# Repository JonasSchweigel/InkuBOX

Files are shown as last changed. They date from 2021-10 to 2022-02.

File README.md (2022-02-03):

# InkuBOX
Creating the InkuBOX was a project we realised in the Makerspace at the TUM School of Life Sciences in Weihenstephan.
We came up with the idea to build a cheap incubator for studying plant-pathogen interactions without contaminating surrounding plants / apperations in the lab / growth chamber.
We descided to follow a modular system and tried to combine modules that are enclosed in themselfes for easy repair / adaption / modulation.
After intensive planning and debating of probable difficulties we started to construct our first prototype.
The control system is realized via the open source arduino platform.
Special parts were designed with AutoDesk360 and printed in PLA with a 3D-Printer.
The project tought us how difficult it can be to develop hardware and how much know how is hidden in every little aspect of even such a small and simple machine. 
We very quicly realized that changing one parameter always influences the whole project. 
We learned how to plan efficiently and what has to be considered if changes in the planing have to be implemented at a later stage.
Every single part of the machine influences the others which can be frustrating but in the end, thats what makes the product work.
This project still has lots of opportunities to be further enhanced and could sometime become the blueprint for a cheap and easy to assable phytochamber for laboratories all around the world.
We hope you find some inspiration through this project and feel free to contact us for any questions.
Starting with the InkuBOX.ptx you will most likely understand the project, even if you do not speak german.

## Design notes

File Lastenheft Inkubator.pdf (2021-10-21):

Lastenheft:

Ein Projekt im Makerspace SoSe2021

Projekt: Inkubator zur Anzucht und Kultivierung von Pflanzen und Pilzen in der Phytopathologie

Name: Jonas Schweigel, Franziska Meyer

Definition: Pflanzen- und Pilzinkubator zur Versuchsdurchführung von Pflanze-Pathogen-Interaktionen

Geschlossenes System mit semi-automatisierter Überwachung und Steuerung verschiedener Umweltfaktoren

Größe: Circa 50cmx75cmx50cm

Sensoren:

- Temperatursensor
- Bodenfeuchtigkeitssensor
- Luftfeuchtigkeitssensor
- Wasserstandsensor

Module:

- Heizung
- Wasserpumpe
- Belüftung (Geeignete Umgebung vorausgesetzt)

Anforderungen

Bewässerung:

- Automatischen Einschalten der Wasserpumpe nach Erreichen eines niedrigen Grenzwerts
- Abschalten der Wasserpumpe bei definiertem Grenzwert
- Überlaufschutz

Heizung:

- Automatisches Einschalten, wenn Temperatur unter Grenzwert fällt
- Abschalten nach Erreichen des Temperaturoptimums

Luftfeuchtigkeit:

- Anzeige der Luftfeuchtigkeit

Gantt Diagramm und Projektplanung

Woche | 1 | 19.04.2021 2 | 26.04.2021 3 | 03.05.2021 4 | 10.05.2021 5 | 17.05.2021 6 | 24.05.2021 7 | 31.05.2021 8 | 07.06.2021 9 | 14.06.2021 10 | 21.06.2021 11 | 28.06.2021 12 | 05.07.2021 13 | 12.07.2021 14 | 19.07.2021 15 | 26.07.2021 16 | Urlaub | 30.08.2021 17 | 06.09.2021 18 | 13.09.2021 19 | 20.09.2021 20 | 27.09.2021 21 | 04.10.2021 22 | 11.10.2021 23 12.04.2021

Phase 1
Projektfindung
Planung und Entwurf
Recherche
Phase 2
Einführung Arduino
Beschaffung Hardware
Codierung
Phase 3
CAD Entwürfe 3D Druck
Zusammenbau Hardware
Zusammenbau Elektronik
Testdurchläufe
Abschluss
Optimierung und Problemanalyse

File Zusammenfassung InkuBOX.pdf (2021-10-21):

Zusammenfassung

InkuBOX - Ein Projekt im Makerspace SoSe2021

Projekt: Inkubator zur Anzucht und Kultivierung von Pflanzen und Pilzen in der Phytopathologie

Name: Jonas Schweigel, Franziska Meyer

Definition: Pflanzen- und Pilzinkubator zur Versuchsdurchführung von Pflanze-Pathogen-Interaktionen

Geschlossenes System mit semi-automatisierter Überwachung und Steuerung verschiedener Umweltfaktoren

Größe: Circa 50cmx75cmx50cm

Sensoren:

- Temperatursensor
- Bodenfeuchtigkeitssensor
- Luftfeuchtigkeitssensor
- Wasserstandsensor

Module:

- Heizung
- Wasserpumpe
- Belüftung (Geeignete Umgebung vorausgesetzt)

Anforderungen

Bewässerung:

- Automatischen Einschalten der Wasserpumpe nach Erreichen eines niedrigen Grenzwerts
- Abschalten der Wasserpumpe bei definiertem Grenzwert
- Überlaufschutz

Heizung:

- Automatisches Einschalten, wenn Temperatur unter Grenzwert fällt
- Abschalten nach Erreichen des Temperaturoptimums

Luftfeuchtigkeit:

- Anzeige der Luftfeuchtigkeit

Gantt Diagramm und Projektplanung

Woche | 1 | 19.04.2021 2 | 26.04.2021 3 | 03.05.2021 4 | 10.05.2021 5 | 17.05.2021 6 | 24.05.2021 7 | 31.05.2021 8 | 07.06.2021 9 | 14.06.2021 10 | 21.06.2021 11 | 28.06.2021 12 | 05.07.2021 13 | 12.07.2021 14 | 19.07.2021 15 | 26.07.2021 16 | Urlaub | 30.08.2021 17 | 06.09.2021 18 | 13.09.2021 19 | 20.09.2021 20 | 27.09.2021 21 | 04.10.2021 22 | 11.10.2021 23 12.04.2021

Phase 1
Projektfindung
Planung und Entwurf
Recherche
Phase 2
Einführung Arduino
Beschaffung Hardware
Codierung
Phase 3
CAD Entwürfe 3D Druck
Zusammenbau Hardware
Zusammenbau Elektronik
Testdurchläufe
Abschluss
Optimierung und Problemanalyse

Darstellung möglicher Erweiterungen/Adaptionen:

- Luftfeuchtigkeit aktiv erhöhen durch Wasserzerstäuber im Innenraum
- Temperierung der zirkulierenden Luft in einem weiteren Modul (Heizmatten außerhalb des

Innenraums)

- Kontrollierte Lichteinstellungen mit Lampe (Steuerung über Funksteckdose)
- Erstellung eines Interfaces, um Paramater je nach Experiment einzustellen (Oder

Programmierung verschiedener Programme, aus welchen man wählen kann)

- PID Regelung des Heizmoduls (Elektronisch regelbares Netzteil bzw. regulierbare Heizmatte)
- Verwendung eines hochwertigeren Bodenfeuchtigkeitssensors
- Verwendung einer vorgefertigten Platine, um Kabel zu reduzieren

Beschränkungen:

- Auf 12 V beschränkte Elektronik
- Elektronik der Feuchte ausgesetzt
- Budget (Kostenaufwand ca. 250-300 Euro)
- Keine aktive Kühlung
- Keine integrierte Lichtquelle
- Keine aktive Beeinflussung der Luftfeuchtigkeit
- Korrosion elektrischer Bauteile im Innenraum des Inkubators
- Weitere Abdichtungen notwendig, um Sporenaustritt vollständig zu verhindern

Fazit:

- Überwachung und Regulation einfacher Umweltfaktoren ist über Arduino Plattform möglich
- Schwierigkeiten beim Design der Hardware zeigten sich sehr schnell
- Software bietet großes Potential für Erweiterungen (PID, Interface, etc.)
- Inkubator eignet sich für Pflanzen und Pilze (Erste Testdurchläufe)

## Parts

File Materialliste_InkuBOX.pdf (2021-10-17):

Materialliste InkuBOX:

Hardware
Aufbewahrungs-/Transportkiste Kunststoff, grau (2x) | Innenmaße (LxBxH): 57x37x21cm Außenmaße (LxBxH): 60x40x22cm
Aufbewahrungs-/Transportkiste Kunststoff, transparent | Außenmaße (LxBxH): 60x40x22cm
Tupperdose (wasserdicht) | Außenmaße (LxBxH): 21x16x9cm
Werkzeugdose | Außenmaße (LxBxH): 24x13x9cm
Abdichtung Handgriffe (3x) | PLA 3D-Druck
Hartschaumplatte | Stärke: 6mm
Bewässerung
Mikrobewässerungssystem; 10 Bewässerungs-Spitzen, Royal Gardeneer

Gartenschlauch Schlauchverbinder
Gartenschlauch | Länge: 100cm; Durchmesser: 13mm
Aquarium Wasserpumpe | 12V DC, 0,67A, 8W
Belüftung
Luftschlauch Silikon | Länge: 400cm Innendurchmesser: 6mm Außendurchmesser: 8mm
Vakuumpumpe (2x) | 12V, 10W, 15L/min
Heizung
Heizmatten Silikon (2x) | 12V DC; 20W; Maße: 20x8cm
Temperatursicherung | 10A, 110°C
Heizmattenaufhänger | PLA 3D-Druck
Sensoren
Bodenfeuchtigkeitssensor AZ Delivery
DHT11 Temperatur- und Luftfeuchtigkeitssensor
Thermistor (Temperatursicherung)
Wasserstandsensor | 3V-5V
Elektronik
Steckdosenleiste (3-Fach) | 250V, 3500W
Netzteil | 12V, 5A, 60W
USB-Netzteil | 5V, 2.5A
USB- Kabel (USB-A auf USB-B)
Elegoo UNO R3 Starter Kit
4 Kanal DC 5V Relaismodul mit Optokoppler
LCD 1602 Modul (Pin Header)
Kontaktschalter DC Power Jack Socket (4x) | Maße 55x21mm
Potentiometer | 10K
Knopfschalter
Mini Breadboard
VGA Stecker und Kabel
Kupferkabel, diverse
Jumperkabel male/female
Schrumpfschläuche, diverse Lüsterklemmen
Sonstiges
Kabelbinder
Schrauben, Unterlegscheibe, Muttern | M8, M6, M4, M2; verschiedene Längen
Eckverbindungsstück, Kunststoff
Dichtungsband

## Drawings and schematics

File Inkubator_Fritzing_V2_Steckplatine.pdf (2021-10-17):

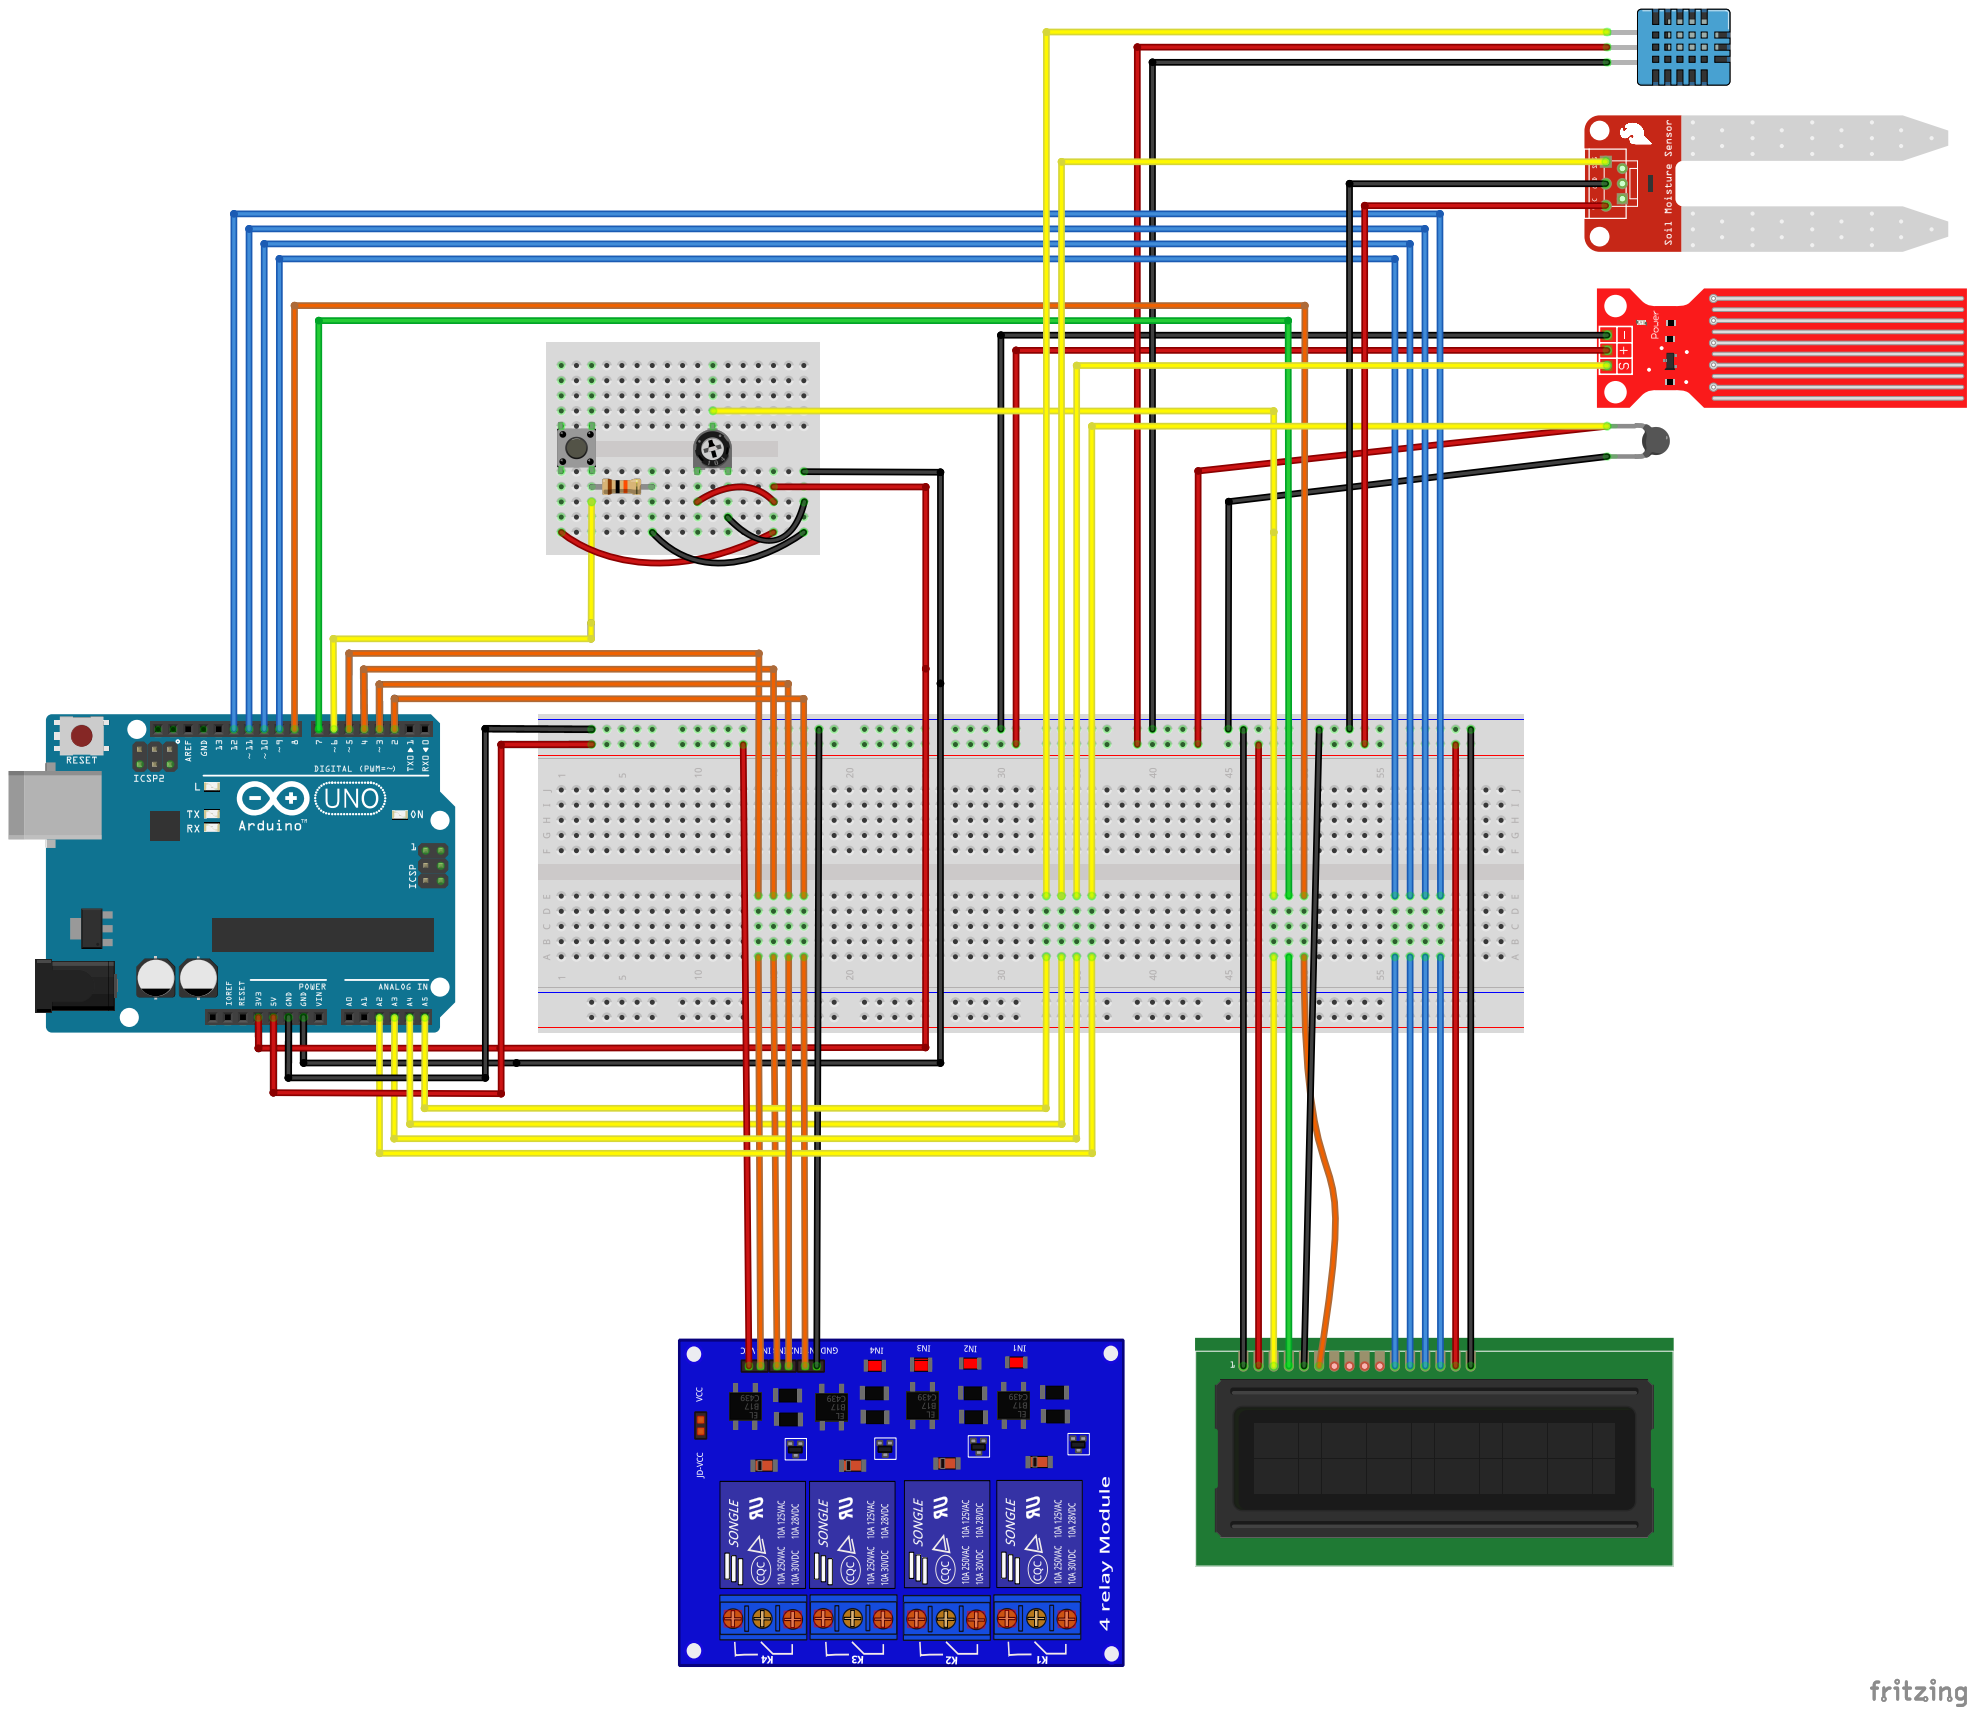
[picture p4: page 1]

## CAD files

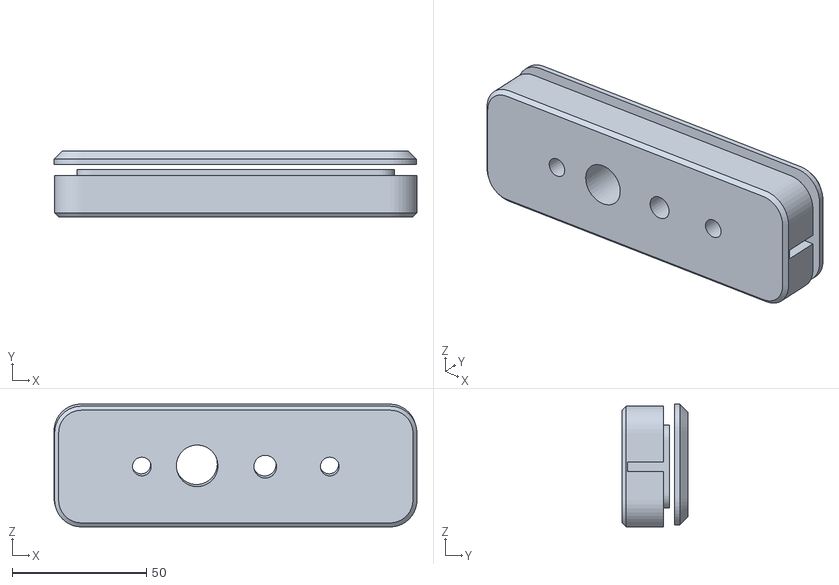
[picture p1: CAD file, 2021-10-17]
Griffabdichtung_GraueBox_Innen- und Außenteil.stl
135.2 x 24.6 x 45.8

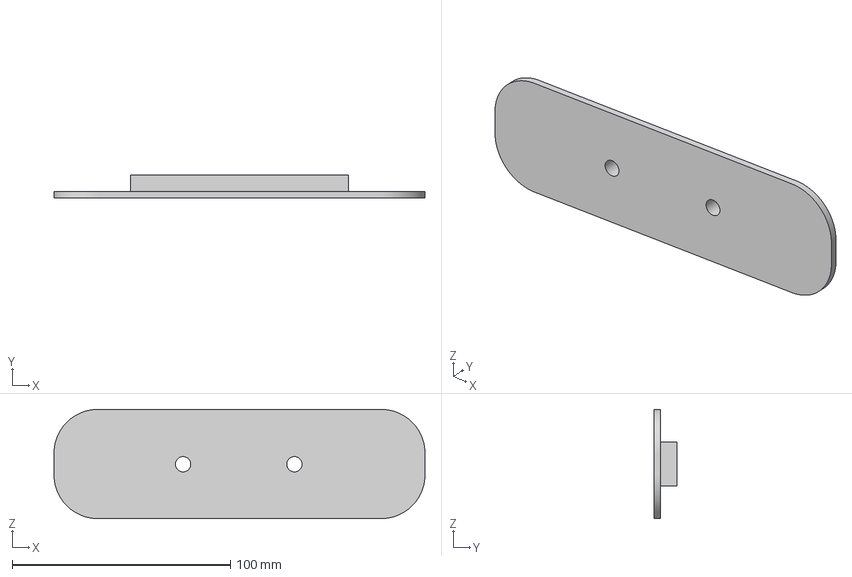
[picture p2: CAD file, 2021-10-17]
Griffabdichtung_TransparenteBox_innen.3mf
170.0 x 10.5 x 50.0 mm

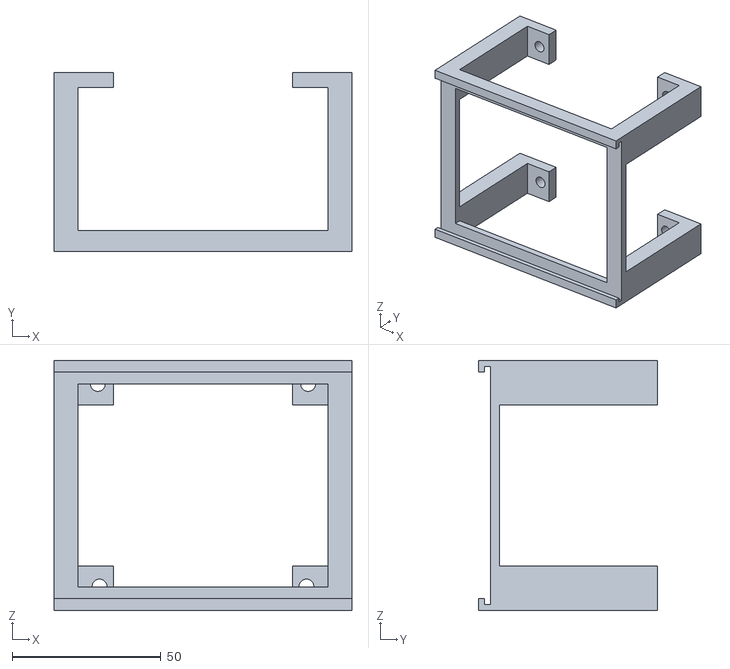
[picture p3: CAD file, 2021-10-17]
Heizmattenaufhänger.stl
100.0 x 60.0 x 84.0

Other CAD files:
Griffabdichtung_TransparenteBox_außen.3mf
